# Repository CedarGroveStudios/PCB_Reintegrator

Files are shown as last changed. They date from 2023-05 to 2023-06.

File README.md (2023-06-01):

# The Reintegrator

### Convert a balanced Class-D speaker-level audio signal to an unbalanced audio line level.

A mono Class-D audio to unbalanced audio line signal output converter. This version can act as a backpack for the Adafruit I2S 3watt audio amplifier.

[The Reintegrator board schematic](https://github.com/CedarGroveStudios/PCB_Reintegrator/blob/main/PCB/breakout.pdf)

OSH Park:
[https://oshpark.com/shared_projects/iI4kd3TW](https://oshpark.com/shared_projects/9TV0nn3f)

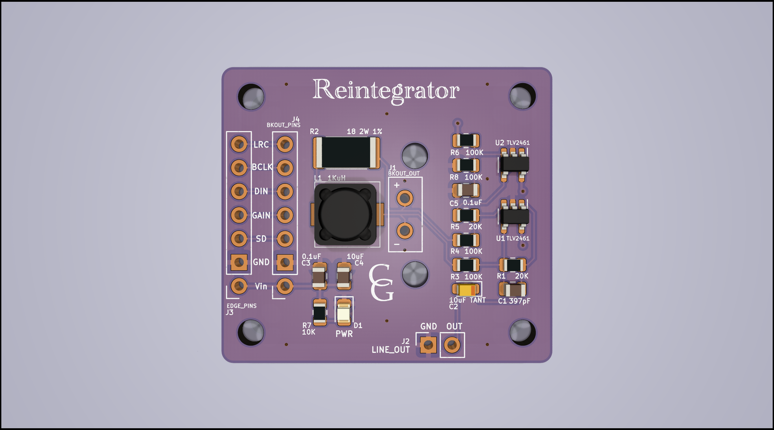
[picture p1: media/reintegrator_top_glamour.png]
The Reintegrator glamour photo


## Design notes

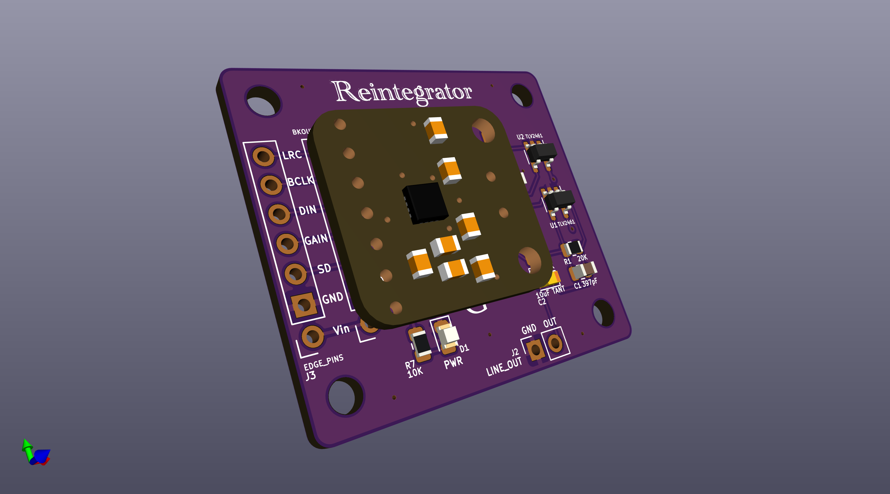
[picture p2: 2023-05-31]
media/reintegrator_with_bkout.png

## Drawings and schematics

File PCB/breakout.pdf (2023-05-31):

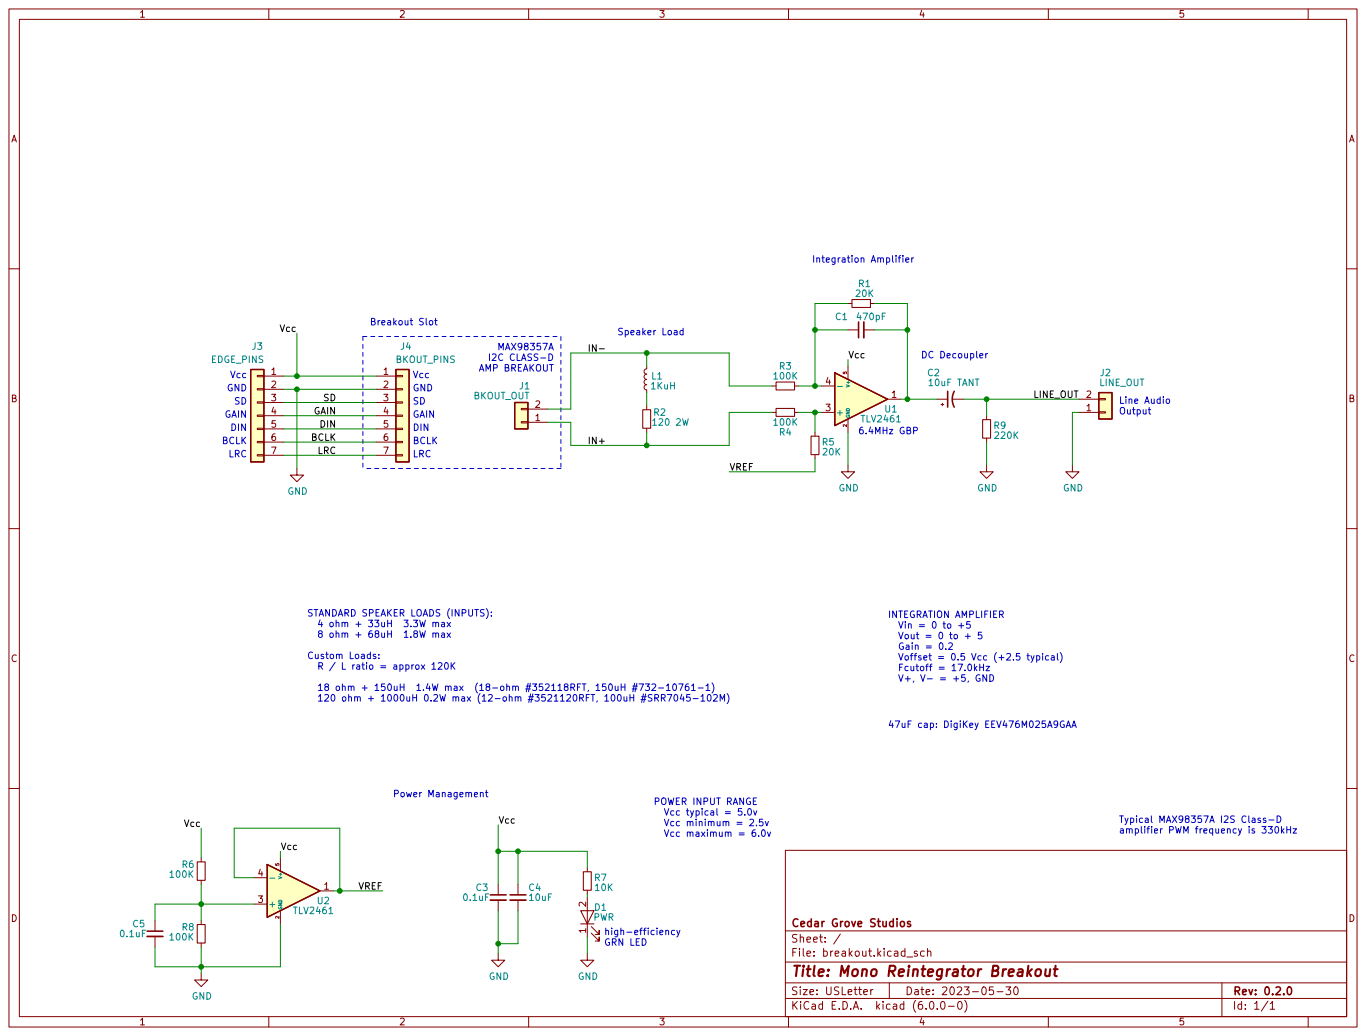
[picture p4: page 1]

Speaker Load Vcc SD GAIN
J3 EDGE_PINS

DC Decoupler GAIN GND
AMP BREAKOUT BCLK

5 | DIN | 5
6 | BCLK | 6
7 | LRC | 7

STANDARD SPEAKER LOADS (INPUTS):
4 ohm + 33uH 3.3W max
8 ohm + 68uH 1.8W max Custom Loads:

Typical MAX98357A I2S Class-D
amplifier PWM frequency is 330kHz

File: breakout.kicad_sch Sheet: / Cedar Grove Studios C3

high-efficiency GRN LED

Id: 1/1 Title: Mono Reintegrator Breakout

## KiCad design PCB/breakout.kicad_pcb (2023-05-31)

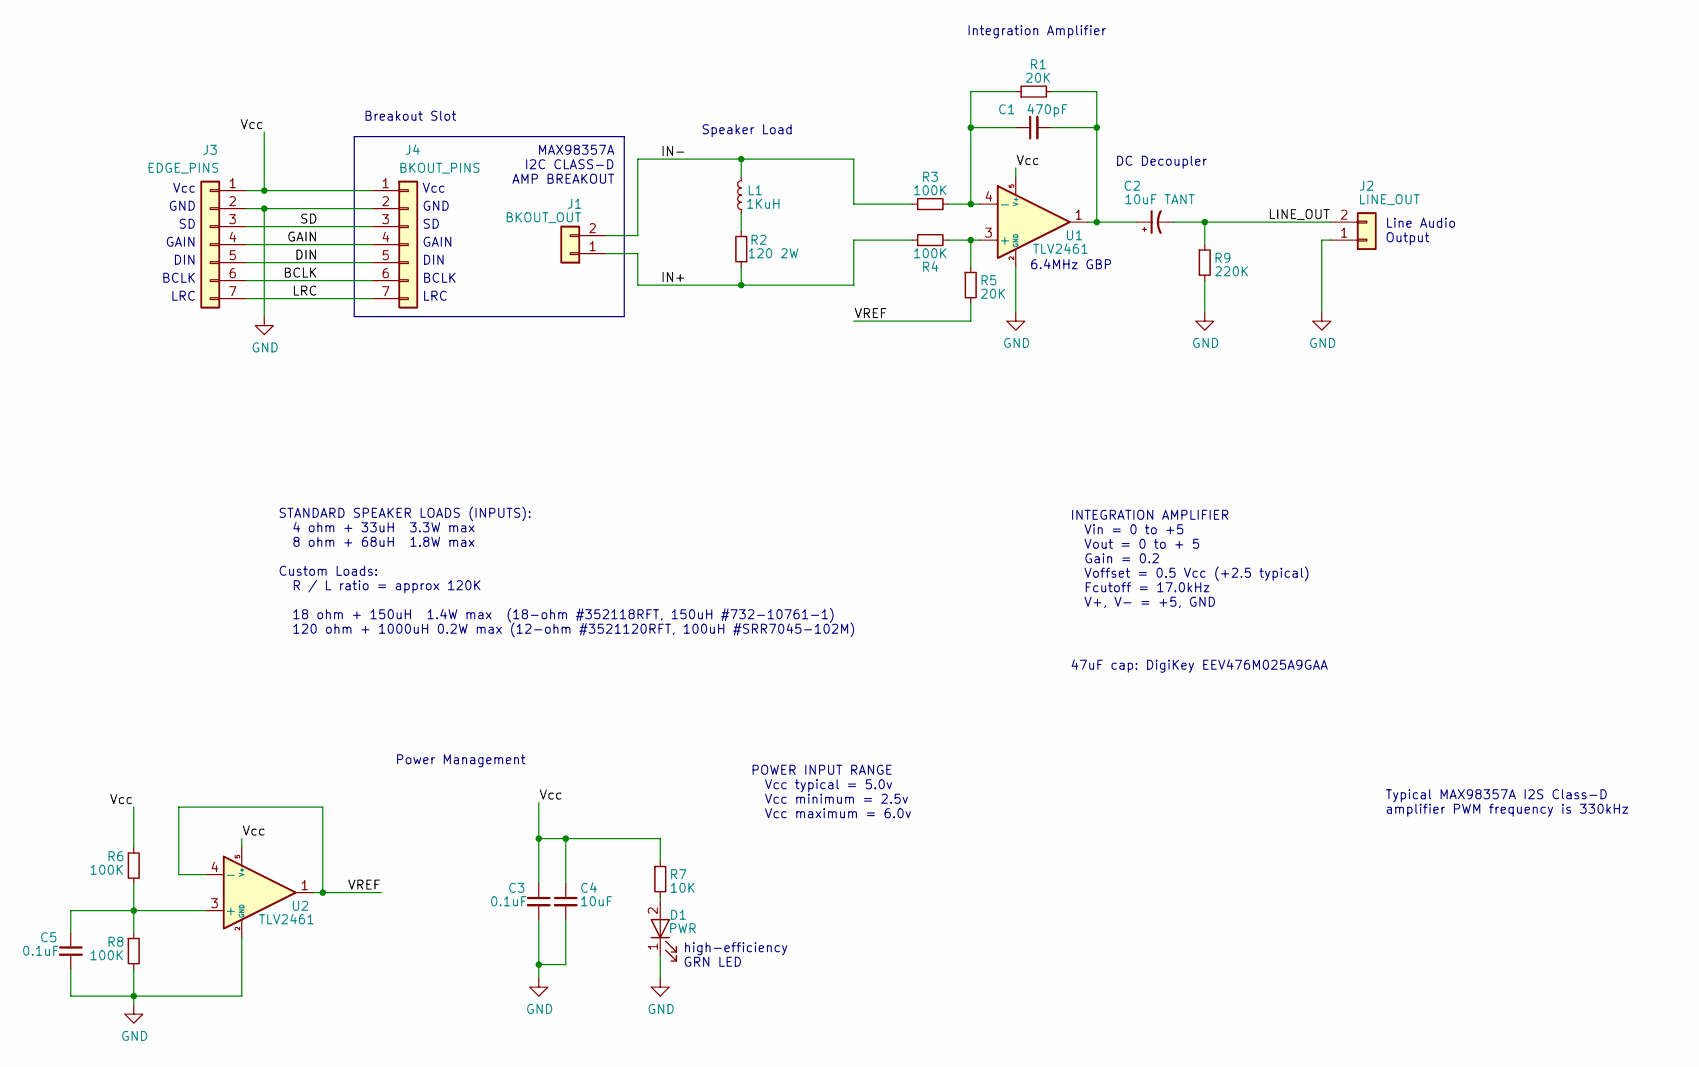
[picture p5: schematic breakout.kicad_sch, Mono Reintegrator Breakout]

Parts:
C1: 470pF; C_0805_2012Metric
C2: 10uF TANT; C_0805_2012Metric
C3, C5: 0.1uF; C_0805_2012Metric
C4: 10uF; C_0805_2012Metric
D1: PWR; LED_0805_2012Metric
J1: BKOUT_OUT; TerminalBlock_4Ucon_1x02_P3.50mm_Vertical
J2: LINE_OUT; PinSocket_1x02_P2.54mm_Vertical
J3: EDGE_PINS; PinSocket_1x07_P2.54mm_Vertical
J4: BKOUT_PINS; PinSocket_1x07_P2.54mm_Vertical
L1: 1KuH; L_Bourns_SRR7045
R1, R5: 20K; R_0805_2012Metric
R2: 120 2W; R_2512_6332Metric
R3, R4, R6, R8: 100K; R_0805_2012Metric
R7: 10K; R_0805_2012Metric
R9: 220K; R_0805_2012Metric
U1, U2: TLV2461; SOT-23-5

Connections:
/BCLK: J3.6, J4.6
/DIN: J3.5, J4.5
/GAIN: J3.4, J4.4
/IN+: J1.1, R2.1, R4.1
/IN-: J1.2, L1.2, R3.1
/LINE_OUT: C2.2, J2.2, R9.1
/LRC: J3.7, J4.7
/SD: J3.3, J4.3
/VREF: R5.2, U2.1, U2.4 (-)
/Vcc: C3.1, C4.1, J3.1, J4.1, R6.1, R7.1, U1.5 (V+), U2.5 (V+)
GND: C3.2, C4.2, C5.2, D1.1 (K), J2.1, J3.2, J4.2, R8.2, R9.2, U1.2 (GND), U2.2 (GND)
unnamed: C1.1, R1.1, R3.2, U1.4 (-)
unnamed: C1.2, C2.1, R1.2, U1.1
unnamed: C5.1, R6.2, R8.1, U2.3 (+)
unnamed: D1.2 (A), R7.2
unnamed: L1.1, R2.2
unnamed: R4.2, R5.1, U1.3 (+)

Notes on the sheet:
GND
high-efficiency GRN LED
LRC
Vcc
INTEGRATION AMPLIFIER Vin = 0 to +5 Vout = 0 to + 5 Gain = 0.2 Voffset = 0.5 Vcc (+2.5 typical) Fcutoff = 17.0kHz V+, V- = +5, GND
GAIN
STANDARD SPEAKER LOADS (INPUTS): 4 ohm + 33uH 3.3W max 8 ohm + 68uH 1.8W max Custom Loads: R / L ratio = approx 120K 18 ohm + 150uH 1.4W max (18-ohm #352118RFT, 150uH #732-10761-1) 120 ohm + 1000uH 0.2W max (12-ohm #3521120RFT, 100uH #SRR7045-102M)
BCLK
DIN
Line Audio Output
MAX98357A I2C CLASS-D AMP BREAKOUT
Integration Amplifier
DC Decoupler
Typical MAX98357A I2S Class-D amplifier PWM frequency is 330kHz
6.4MHz GBP
Power Management
POWER INPUT RANGE Vcc typical = 5.0v Vcc minimum = 2.5v Vcc maximum = 6.0v
47uF cap: DigiKey EEV476M025A9GAA
Breakout Slot
Speaker Load

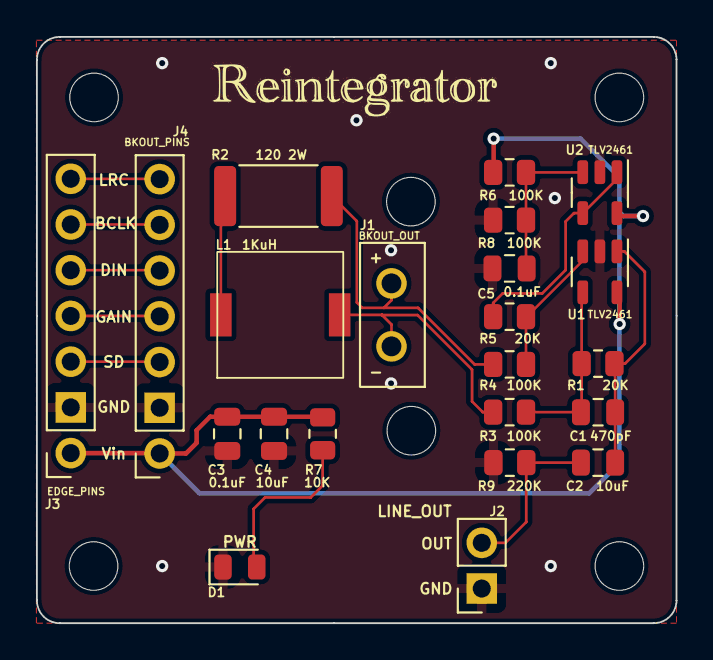
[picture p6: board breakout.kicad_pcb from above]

Board: 2 copper layers, 35.5 x 32.6 mm, 22 parts (0 on the bottom side), 17 nets.

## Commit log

2023-05-31 initial repo load
    [breakout-B_Cu.gbl, breakout-B_Mask.gbs, breakout-B_Silkscreen.gbo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]
2023-06-01 update kicad backups
